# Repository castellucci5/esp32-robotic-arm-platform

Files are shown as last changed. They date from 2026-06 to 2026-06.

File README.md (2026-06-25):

# ESP32 Robotic Arm Platform

<p align="center">
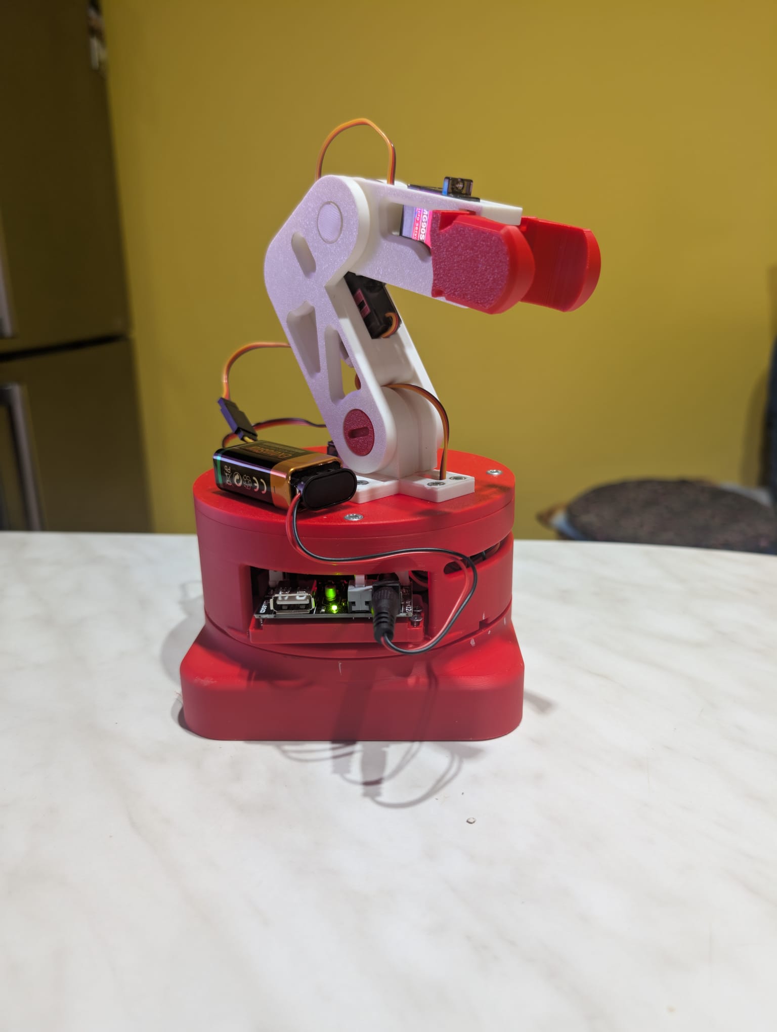
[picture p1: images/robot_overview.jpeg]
  
</p>
<p align="center">
<b>Custom evolution of the L-ONE Cyberbrick Desktop Robotic Arm</b><br>
Mechanical redesign • Embedded electronics • ESP32 firmware • Web interface
</p>

---

# Overview

This project is a complete redesign of the original **L-ONE Cyberbrick Desktop Robotic Arm**.

Instead of simply assembling the original model, the goal was to redesign the platform by improving its mechanical structure, integrating custom electronics inside the base and developing a completely new control architecture based on an ESP32 microcontroller.

The result is a cleaner, stronger and more modular robotic platform that can be controlled directly from any web browser through a local WiFi network.

---

# Why this project?

The original L-ONE Cyberbrick project is an excellent educational robotic platform.

This repository documents how it has been transformed into a completely customized version by redesigning several mechanical components, integrating embedded electronics and developing custom firmware.

Every modification presented here has been designed, manufactured and tested during the development of this project.

---

# Highlights

- 🤖 Complete mechanical redesign
- ⚡ ESP32-based control architecture
- 🌐 Browser-based WiFi control
- 🎛️ PCA9685 servo controller
- ⚙️ Stepper motor upgrade
- 🔩 Reinforced mechanical structure
- 🏗️ Internal electronics compartment
- 📚 Fully documented CAD files

---

# Mechanical Improvements

<p align="center">
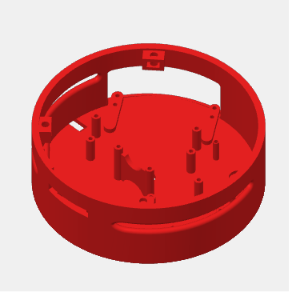
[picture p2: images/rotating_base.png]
  
</p>

Compared to the original project, the following improvements have been implemented.

## Base Assembly

- Enlarged fixed base
- Enlarged rotating base
- Internal compartment for electronics
- Integrated power distribution
- External ELEGOO power switch

## Base Rotation

<p align="center">
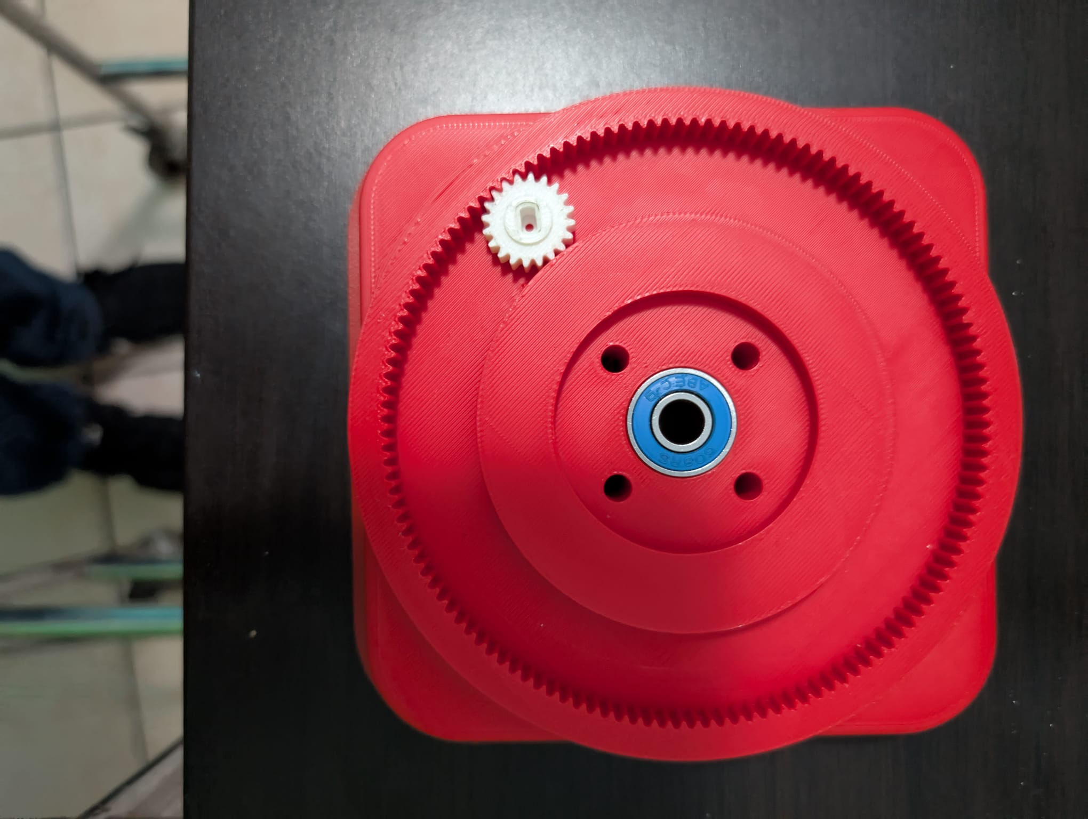
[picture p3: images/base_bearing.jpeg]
  
</p>

The rotating base has been redesigned by introducing:

- Bearing support
- 28BYJ-48 stepper motor
- ULN2003 driver
- Improved structural rigidity

## Joint 1 Redesign

<p align="center">
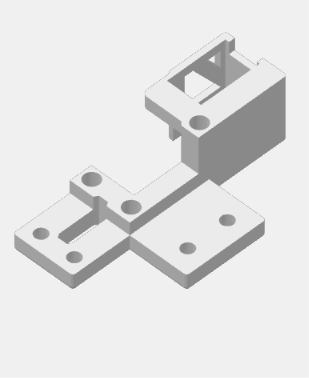
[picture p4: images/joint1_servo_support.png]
  
</p>

The original servo holder has been completely redesigned.

The servo motor is now mounted on an independent support instead of being integrated into the rotating cover.

This solution improves:

- maintenance
- accessibility
- structural rigidity

## Mechanical Reinforcement

Critical structural points have been redesigned using screw fasteners.

This solution significantly improves the robustness of the entire robotic arm compared to the original design.

---

# Electronics Integration

<p align="center">
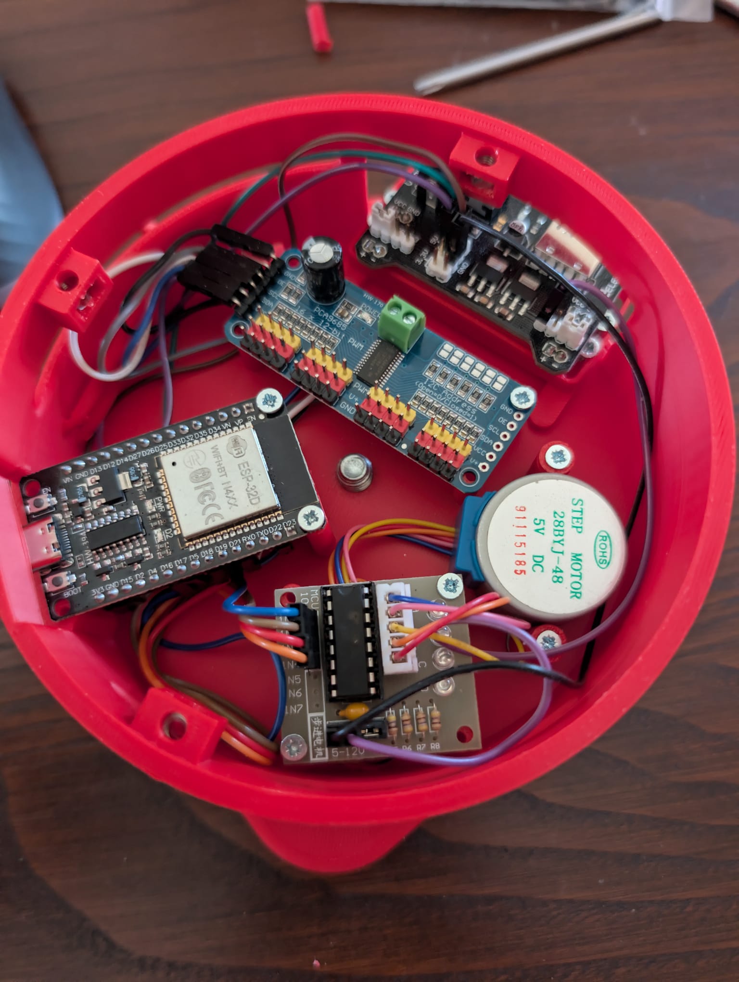
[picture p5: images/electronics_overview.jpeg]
  
</p>

The enlarged rotating base houses all control electronics.

Integrated hardware:

- ESP32
- PCA9685 Servo Driver
- ULN2003 Stepper Driver
- ELEGOO MB V2

The result is a compact and protected embedded control system.

---

# Software Architecture

<p align="center">
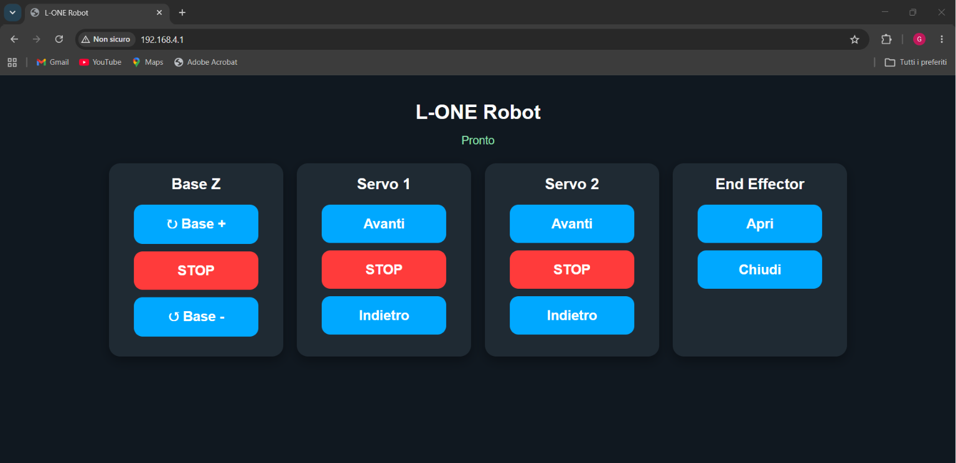
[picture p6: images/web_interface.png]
  
</p>

A completely custom firmware has been developed for ESP32.

Main features:

- Local WiFi Access Point
- Embedded Web Server
- Browser-based robot control
- Servo control
- Stepper motor control
- HTML
- CSS
- JavaScript
- LittleFS filesystem

---

# Hardware Architecture

```text
                Browser
                   │
              WiFi Network
                   │
                ESP32
        ┌──────────┴──────────┐
        │                     │
    PCA9685               ULN2003
        │                     │
 Servo Motors          Stepper Motor
```

---

# Repository Structure

```text
cad/
│
├── 3mf_files/
└── solidworks/

firmware/

images/

web_interface/
```

---

# Technologies

## Embedded

- ESP32
- Arduino Framework
- PCA9685
- ULN2003
- LittleFS

## Software

- HTML
- CSS
- JavaScript

## CAD

- SolidWorks
- Bambu Studio
- 3D Printing

## Robotics

- Servo Motors
- Stepper Motors
- Embedded Integration

---

# Project Status

## ✅ Version 1.0 — First Complete Prototype

Implemented features:

- Complete mechanical redesign
- Embedded electronics integration
- ESP32 firmware
- Browser-based control
- Ready-to-print CAD files
- Complete project documentation

---

# Future Development

## Branch A

Linear fourth axis.

## Branch B

Integration with Makerslab Arm Robot Control.

---

# Gallery

<p align="center">
  
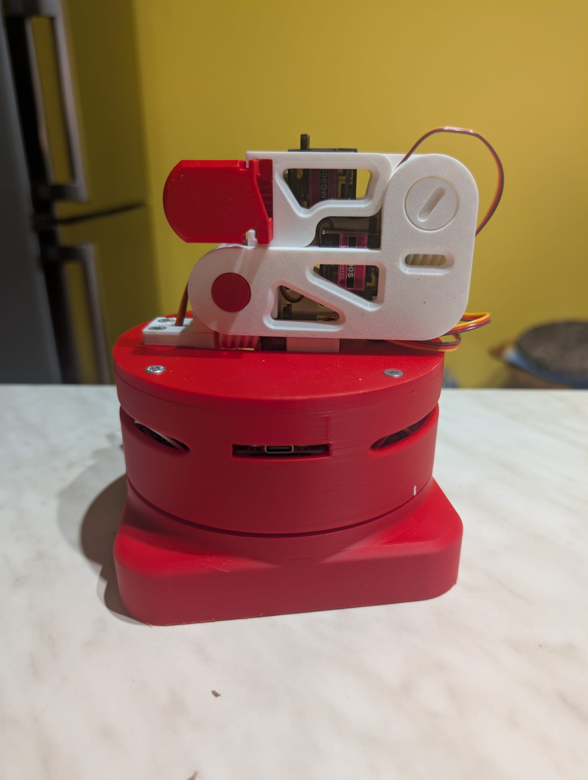
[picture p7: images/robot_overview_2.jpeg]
  
</p>

---

# Acknowledgements

This project is based on the original **L-ONE Cyberbrick Desktop Robotic Arm**.

This repository documents all custom mechanical, electronic and software developments introduced during the creation of this robotic platform.

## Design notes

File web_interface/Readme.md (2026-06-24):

# WEB PAGE

The Web page was implemented by files :
- index.html
- style.css
- script.js

These files are uploaded on ESP32 by LittleFS:
<br>
`\Arduino_Project_Directory`
- Firmware                        
`\data`
- index.html
- style.css
- script.js

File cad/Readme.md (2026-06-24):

# CAD Files

This directory contains all CAD-related resources for the project.

## Folder Structure

- `3mf/` → Bambu Studio project files
- `step/` → STEP files
- `stl/` → STL files
- `solidworks/` → Native CAD files

## Bambu Studio Files

⚠️ Some parts require a scale factor of **105%** in Bambu Studio.

Only the following files need to be scaled to 105%:

- `braccio1.3mf`
- `braccio2.3mf`
- `cover_braccio_1.3mf`
- `pinza_destra_e_sinistra_uguali.3mf`
- `ingranaggio_pinza.3mf`
- `vite_di_fissaggio_giunto_2.3mf`
- `vite_giunto_1.3mf`

All remaining files should be printed at 100% scale.

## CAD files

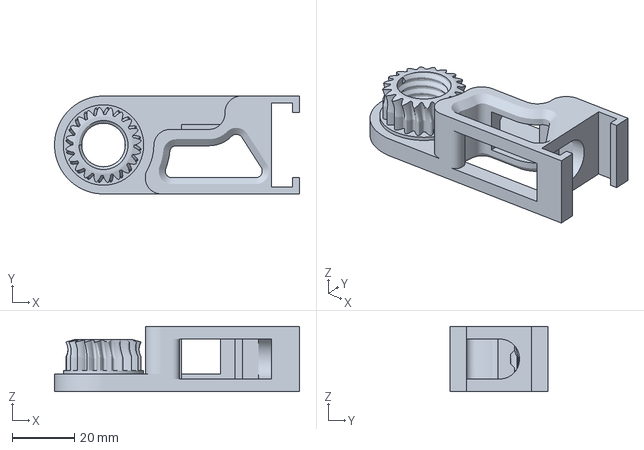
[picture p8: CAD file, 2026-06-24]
cad/3mf_files/braccio2.3mf
78.8 x 31.5 x 20.9 mm

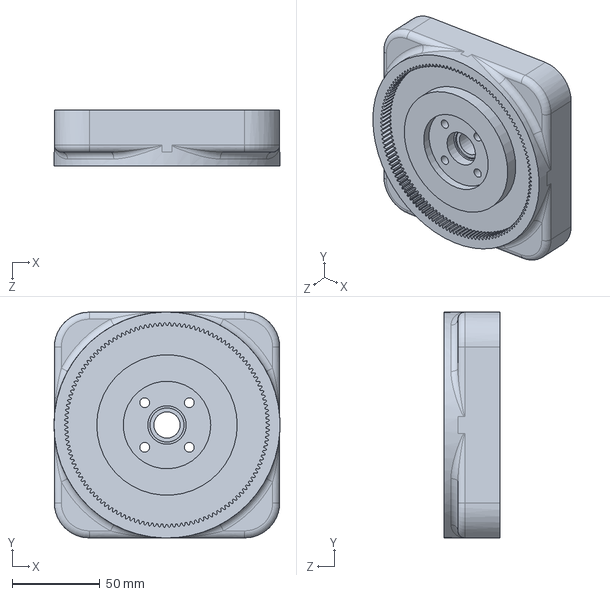
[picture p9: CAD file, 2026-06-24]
cad/solidWorks/Nuova_base.SLDPRT
129.0 x 128.9 x 32.0 mm

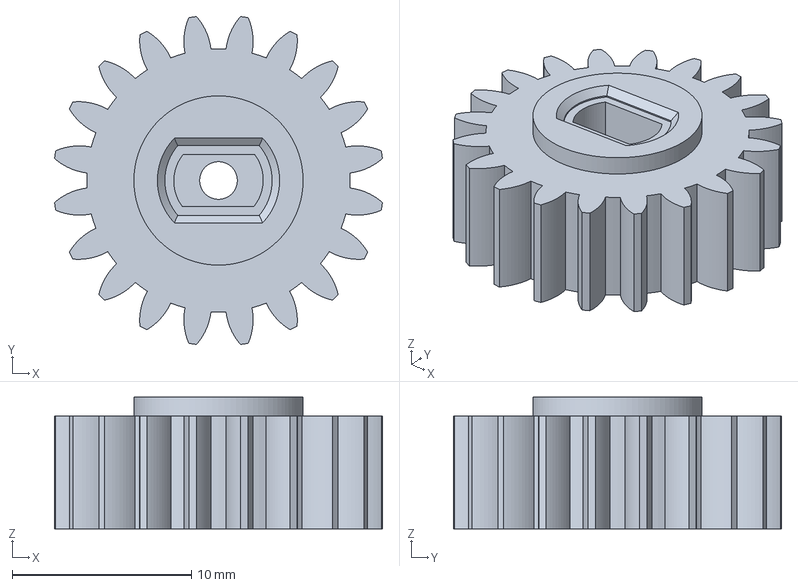
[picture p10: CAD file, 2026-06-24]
cad/3mf_files/ingranaggio_della_base.3mf
18.3 x 18.3 x 7.35 mm

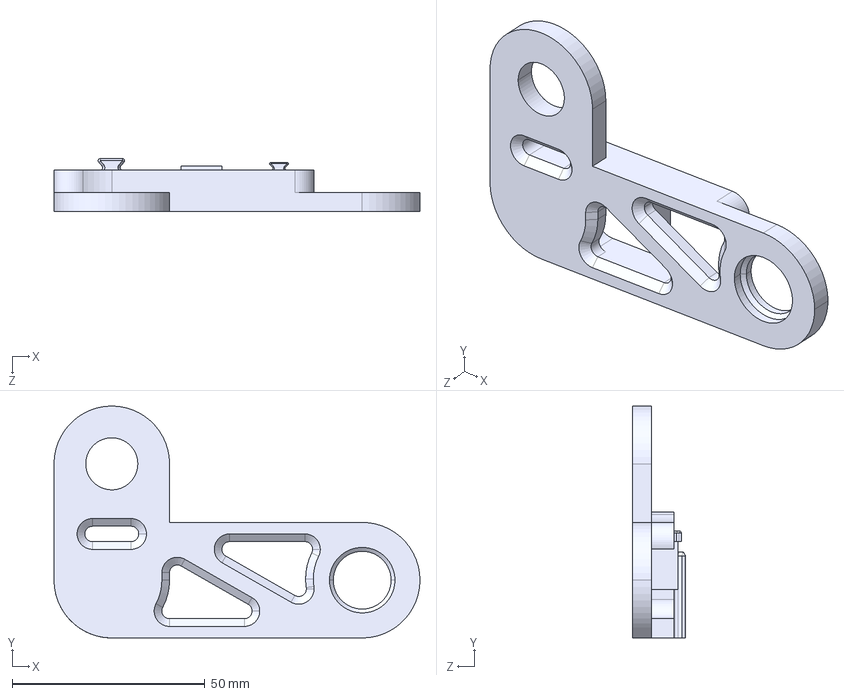
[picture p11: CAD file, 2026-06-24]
cad/solidWorks/lower_arm_cover.STEP
95.0 x 60.2 x 13.8 mm

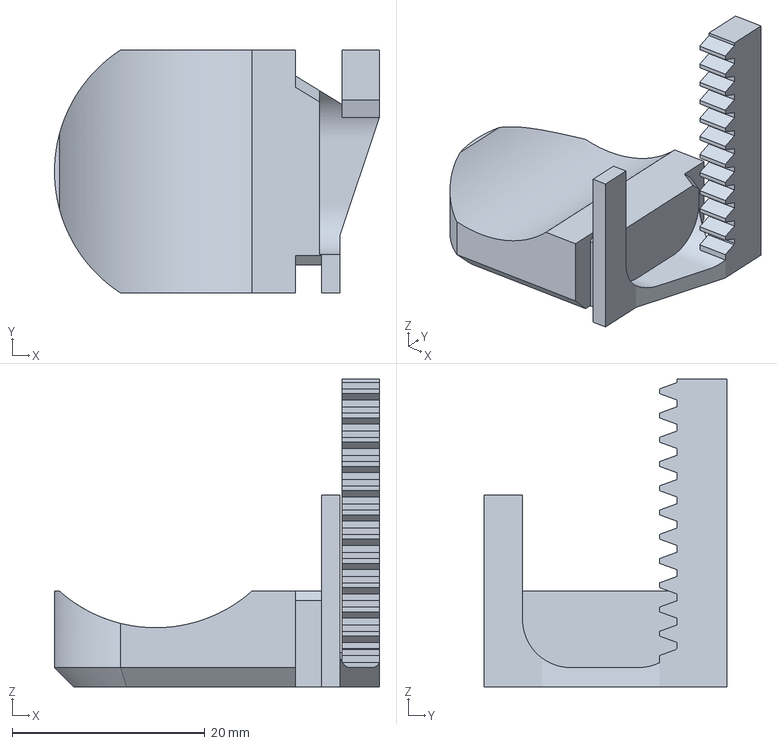
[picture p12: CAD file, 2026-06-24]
cad/3mf_files/pinza_destra_e_sinstra_uguali.3mf
33.7 x 25.2 x 31.9 mm

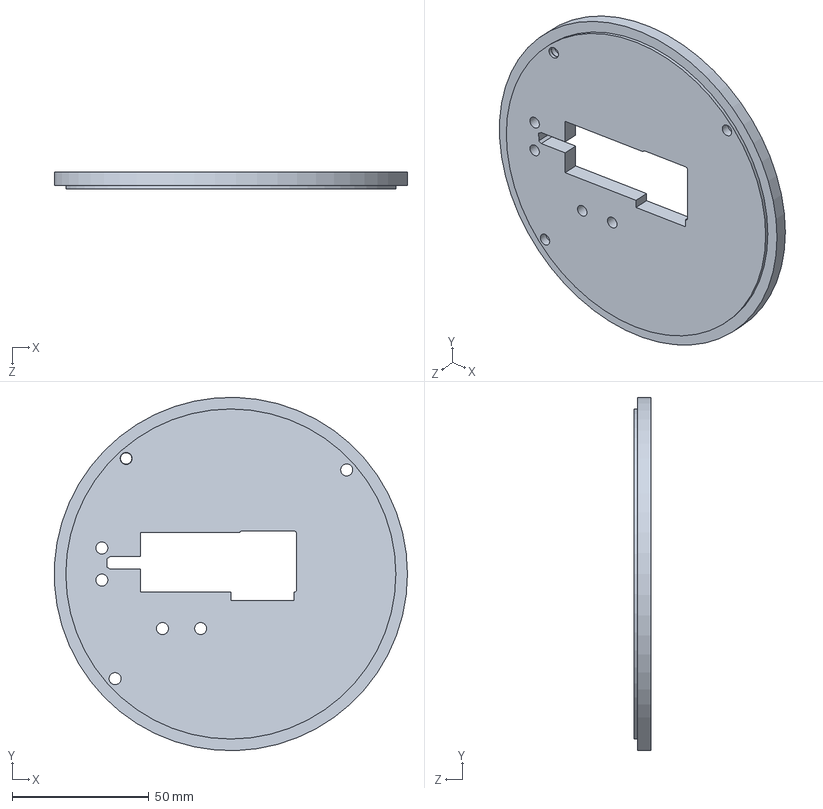
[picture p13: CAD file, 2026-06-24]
cad/solidWorks/coperchio_base.SLDPRT
128.9 x 128.9 x 6.30 mm

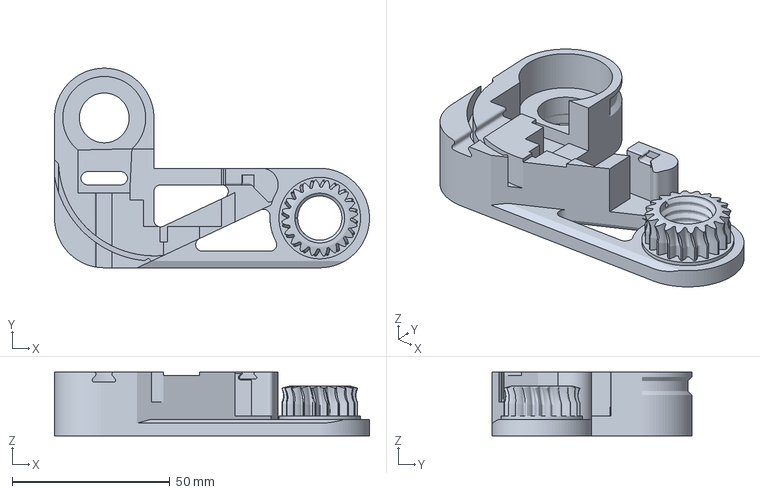
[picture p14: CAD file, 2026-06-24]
cad/3mf_files/braccio1.3mf
99.8 x 63.2 x 20.2 mm

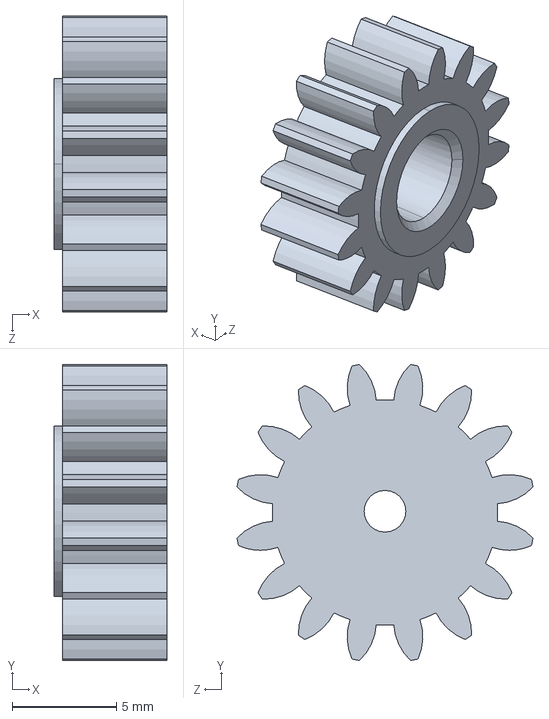
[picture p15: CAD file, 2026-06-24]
cad/solidWorks/ingranaggio_pinza.SLDPRT
5.40 x 14.2 x 14.2 mm

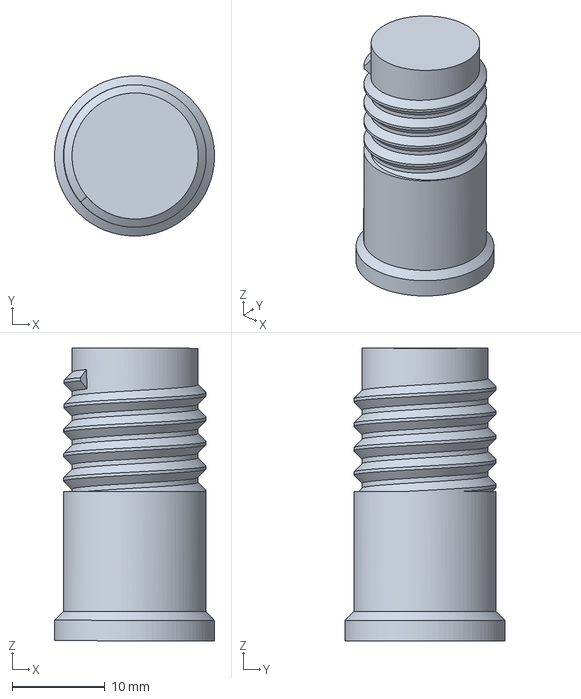
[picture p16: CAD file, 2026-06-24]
cad/3mf_files/vite_giunto_1.3mf
17.2 x 17.2 x 31.5 mm

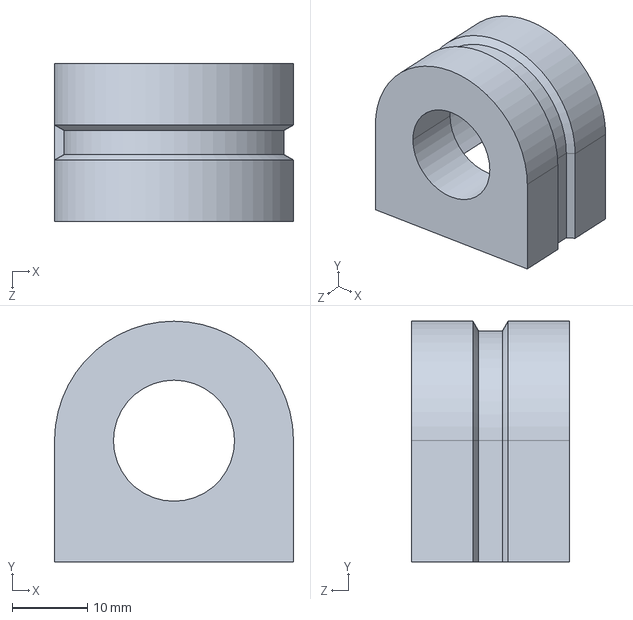
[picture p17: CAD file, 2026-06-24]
cad/solidWorks/case_giunto_1_modificato.SLDPRT
31.8 x 32.0 x 21.0 mm

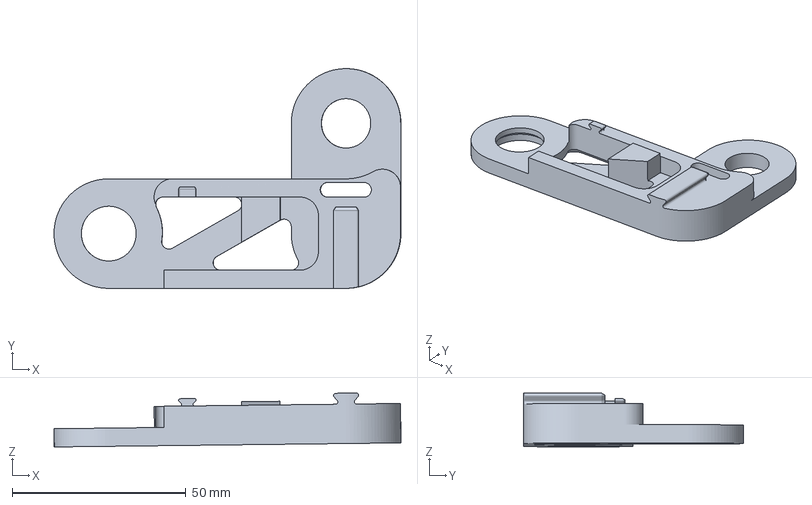
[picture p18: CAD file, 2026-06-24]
cad/3mf_files/cover_braccio_1.3mf
99.8 x 63.2 x 15.5 mm

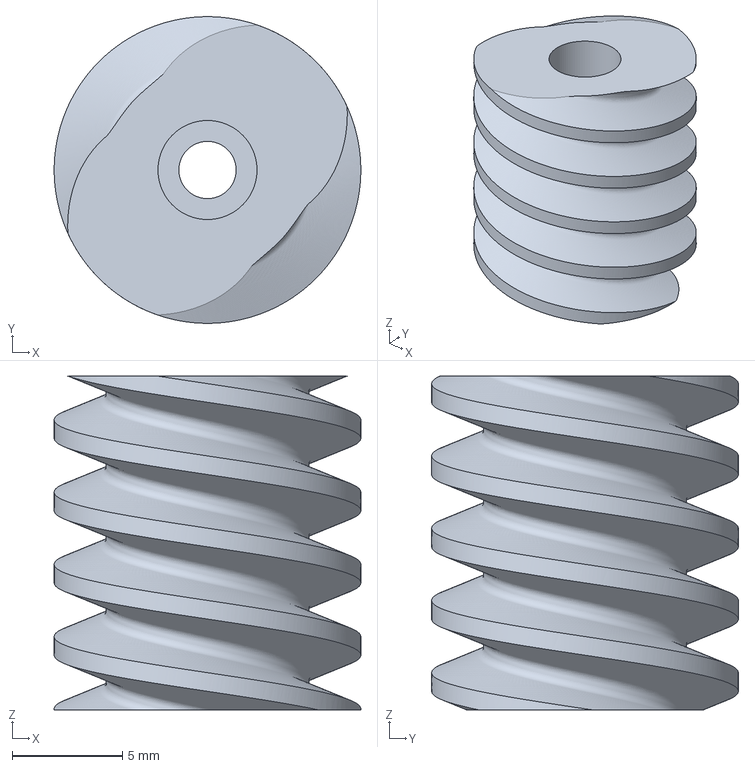
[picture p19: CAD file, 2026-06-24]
cad/3mf_files/vite_senza_fine_con_vite_di_bloccaggio.3mf
13.9 x 13.9 x 15.2 mm

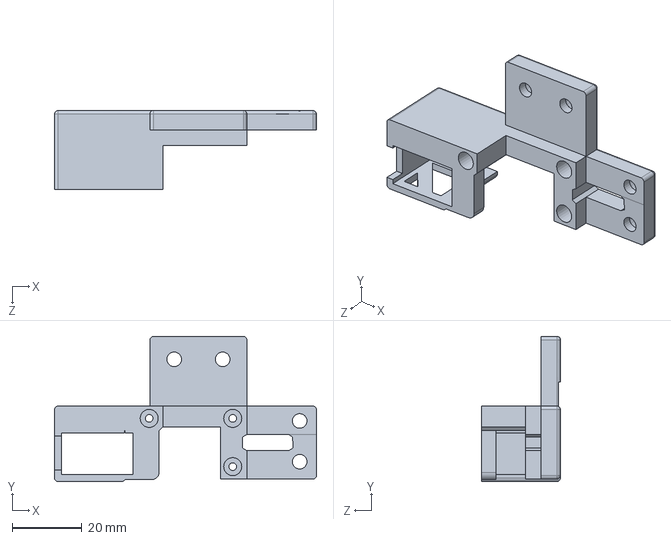
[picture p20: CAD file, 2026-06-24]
cad/solidWorks/supporto_servo_arm_1.SLDPRT
75.3 x 41.7 x 22.8 mm

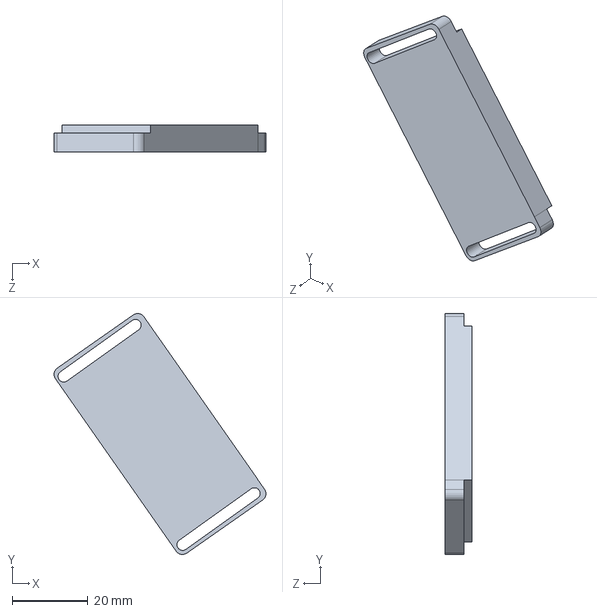
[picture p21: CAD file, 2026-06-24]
cad/solidWorks/adattatore_elego.SLDPRT
55.9 x 63.5 x 7.00 mm

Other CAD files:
cad/solidWorks/gripper_gear.STEP
cad/3mf_files/vite_di_fissaggio_giunto_2.3mf
cad/solidWorks/boccola_cuscinetto.SLDPRT
cad/solidWorks/flangia_cuscinetto_base.SLDPRT
cad/3mf_files/Nuova_base.3mf
cad/3mf_files/adattatore_elego.3mf
cad/3mf_files/base_rotante.3mf
cad/3mf_files/boccola_cuscinetto.3mf
cad/3mf_files/case_giunto_1_modificato.3mf
cad/3mf_files/coperchio_base.3mf
cad/3mf_files/fissaggio_stepper_motor.3mf
cad/3mf_files/flangia_cuscinetto_base.3mf
cad/3mf_files/ingranaggio_pinza.3mf
cad/3mf_files/supporto_servo_arm_1.3mf
cad/solidWorks/Vite_senza_fine_con_fissaggio.SLDPRT
cad/solidWorks/base_rotante.SLDPRT
cad/solidWorks/fissaggio_stepper_motor.SLDPRT
cad/solidWorks/gripper_left_right_same.STEP
cad/solidWorks/lower_arm_screw.STEP
cad/solidWorks/upper_arm_screw.STEP

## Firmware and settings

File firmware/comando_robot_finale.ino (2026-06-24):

#include <WiFi.h>
#include <Wire.h>
// #include <Stepper.h>
#include <AccelStepper.h>
#include <Adafruit_PWMServoDriver.h>
#include <LittleFS.h>

// ===== WiFi =====
const char* ssid = "LONE_ROBOT";
const char* password = "12345678";

WiFiServer server(80);

// ===== PCA9685 =====
Adafruit_PWMServoDriver pwm = Adafruit_PWMServoDriver(0x40);

#define SERVO_FREQ 50

#define SERVO1_CH 0
#define SERVO2_CH 1
#define GRIPPER_CH 2

// Servo 1
#define SERVO1_STOP_US 1480
#define SERVO1_FWD_US  800
#define SERVO1_REV_US  2300

// Servo 2
#define SERVO2_STOP_US 1500
#define SERVO2_FWD_US  1850
#define SERVO2_REV_US  1300

// Gripper 180°
#define GRIPPER_OPEN_US   1600
#define GRIPPER_CLOSE_US  750

// ===== Stepper 28BYJ-48 + ULN2003 =====
const int IN1 = 16;
const int IN2 = 18;
const int IN3 = 17;
const int IN4 = 19;

//const int stepsPerRevolution = 2048;

const float BASE_SPEED = 512; // circa equivalente a 15 rpm con 2048 step/rev default 1024


// Ordine fasi trovato funzionante
//Stepper baseStepper(stepsPerRevolution, IN1, IN4, IN3, IN2);
// Ordine fasi trovato funzionante

AccelStepper baseStepper(AccelStepper::HALF4WIRE, IN1, IN4, IN3, IN2);

// int baseSpeedRpm = 15;

// Da calibrazione:
// 3500 step ≈ 90°
// quindi 1750 step ≈ 45°
#define BASE_45_STEPS 1750

// ===== Funzioni =====
int usToTicks(int us) {
  return (int)(us * 4096L / 20000L);
}

void writeServoUS(int ch, int us) {
  pwm.setPWM(ch, 0, usToTicks(us));
}

void releaseStepper() {
  baseStepper.setSpeed(0);

  digitalWrite(16, LOW);
  digitalWrite(17, LOW);
  digitalWrite(18, LOW);
  digitalWrite(19, LOW);
}

void setup() {
  Serial.begin(115200);
  // Montaggio del file system
  LittleFS.begin(true);
  // I2C ESP32
  Wire.begin(21, 22);

  // PCA9685
  pwm.begin();
  pwm.setPWMFreq(SERVO_FREQ);
  delay(500);

  writeServoUS(SERVO1_CH, SERVO1_STOP_US);
  writeServoUS(SERVO2_CH, SERVO2_STOP_US);
  writeServoUS(GRIPPER_CH, GRIPPER_OPEN_US);

  // Stepper
  pinMode(16, OUTPUT);
  pinMode(17, OUTPUT);
  pinMode(18, OUTPUT);
  pinMode(19, OUTPUT);

  //baseStepper.setSpeed(baseSpeedRpm);
  //releaseStepper();

  baseStepper.setMaxSpeed(BASE_SPEED);
  baseStepper.setSpeed(0);

  

  // WiFi AP
  WiFi.softAP(ssid, password);

  Serial.println("WiFi creato");
  Serial.print("Connettiti a: ");
  Serial.println(ssid);
  Serial.print("Apri browser su: http://");
  Serial.println(WiFi.softAPIP());

  server.begin();
}

void loop() {
  baseStepper.runSpeed();
  
  WiFiClient client = server.available();
  if (!client) return;

  String req = client.readStringUntil('\r');
  client.flush();

  String path = req.substring(req.indexOf("GET ") + 4, req.indexOf(" HTTP"));

  if (path == "/BASE_P") {
    baseStepper.setSpeed(BASE_SPEED);
    sendText(client, "BASE +");
  }
  else if (path == "/BASE_M") {
    baseStepper.setSpeed(-BASE_SPEED);
    sendText(client, "BASE -");
  }
  else if (path == "/BASE_STOP") {
    releaseStepper();
    sendText(client, "BASE STOP");
  }
  else if (path == "/S1A") {
    writeServoUS(SERVO1_CH, SERVO1_FWD_US);
    sendText(client, "SERVO 1 AVANTI");
  }
  else if (path == "/S1S") {
    writeServoUS(SERVO1_CH, SERVO1_STOP_US);
    sendText(client, "SERVO 1 STOP");
  }
  else if (path == "/S1D") {
    writeServoUS(SERVO1_CH, SERVO1_REV_US);
    sendText(client, "SERVO 1 INDIETRO");
  }
  else if (path == "/S2A") {
    writeServoUS(SERVO2_CH, SERVO2_FWD_US);
    sendText(client, "SERVO 2 AVANTI");
  }
  else if (path == "/S2S") {
    writeServoUS(SERVO2_CH, SERVO2_STOP_US);
    sendText(client, "SERVO 2 STOP");
  }
  else if (path == "/S2D") {
    writeServoUS(SERVO2_CH, SERVO2_REV_US);
    sendText(client, "SERVO 2 INDIETRO");
  }
  else if (path == "/OPEN") {
    writeServoUS(GRIPPER_CH, GRIPPER_OPEN_US);
    sendText(client, "GRIPPER APERTO");
  }
  else if (path == "/CLOSE") {
    writeServoUS(GRIPPER_CH, GRIPPER_CLOSE_US);
    sendText(client, "GRIPPER CHIUSO");
  }
  else if (path == "/style.css") {
    serveFile(client, "/style.css", "text/css");
  }
  else if (path == "/script.js") {
    serveFile(client, "/script.js", "application/javascript");
  }
  else {
    serveFile(client, "/index.html", "text/html");
  }
  

  // ===== BASE =====
  //   if (req.indexOf("/BASE_P") != -1) {
  //   Serial.println("BASE ORARIO CONTINUO");
  //   baseStepper.setSpeed(BASE_SPEED);
  // }
  
  // if (req.indexOf("/BASE_M") != -1) {
  //   Serial.println("BASE ANTIORARIO CONTINUO");
  //   baseStepper.setSpeed(-BASE_SPEED);
  // }
  
  // if (req.indexOf("/BASE_STOP") != -1) {
  //   Serial.println("BASE STOP");
  //   releaseStepper();
  // }

  // // ===== SERVO 1 =====
  // if (req.indexOf("/S1A") != -1) {
  //   writeServoUS(SERVO1_CH, SERVO1_FWD_US);
  //   Serial.println("SERVO 1 AVANTI");
  // }

  // if (req.indexOf("/S1S") != -1) {
  //   writeServoUS(SERVO1_CH, SERVO1_STOP_US);
  //   Serial.println("SERVO 1 STOP");
  // }

  // if (req.indexOf("/S1D") != -1) {
  //   writeServoUS(SERVO1_CH, SERVO1_REV_US);
  //   Serial.println("SERVO 1 INDIETRO");
  // }

  // // ===== SERVO 2 =====
  // if (req.indexOf("/S2A") != -1) {
  //   writeServoUS(SERVO2_CH, SERVO2_FWD_US);
  //   Serial.println("SERVO 2 AVANTI");
  // }

  // if (req.indexOf("/S2S") != -1) {
  //   writeServoUS(SERVO2_CH, SERVO2_STOP_US);
  //   Serial.println("SERVO 2 STOP");
  // }

  // if (req.indexOf("/S2D") != -1) {
  //   writeServoUS(SERVO2_CH, SERVO2_REV_US);
  //   Serial.println("SERVO 2 INDIETRO");
  // }

  // // ===== GRIPPER =====
  // if (req.indexOf("/OPEN") != -1) {
  //   writeServoUS(GRIPPER_CH, GRIPPER_OPEN_US);
  //   Serial.println("GRIPPER APERTO");
  // }

  // if (req.indexOf("/CLOSE") != -1) {
  //   writeServoUS(GRIPPER_CH, GRIPPER_CLOSE_US);
  //   Serial.println("GRIPPER CHIUSO");
  // }

  // ===== PAGINA WEB =====
  // File f = LittleFS.open("/index.html", "r");

  // client.println("HTTP/1.1 200 OK");
  // client.println("Content-Type: text/html");
  // client.println();

  // while (f.available()) {
  //     client.write(f.read());
  // }

  // f.close();

  // client.println("HTTP/1.1 200 OK");
  // client.println("Content-type:text/html");
  // client.println();

  // client.println("<!DOCTYPE html><html>");
  // client.println("<head><meta name='viewport' content='width=device-width, initial-scale=1'>");

  // client.println("<style>");
  // client.println("body{font-family:Arial;text-align:center;margin-top:25px;}");
  // client.println(".container{display:flex;justify-content:center;gap:25px;flex-wrap:wrap;}");
  // client.println(".box{border:1px solid #999;border-radius:12px;padding:18px;width:260px;}");
  // client.println("button{font-size:24px;padding:18px;margin:8px;width:210px;}");
  // client.println("</style></head>");

  // client.println("<body>");
  // client.println("<h1>L-ONE Robot Test</h1>");

  // client.println("<div class='container'>");

  // client.println("<div class='box'>");
  // client.println("<h2>Base Z</h2>");
  // client.println("<p><a href='/BASE_P'><button>+</button></a></p>");
  // client.println("<p><a href='/BASE_STOP'><button>STOP</button></a></p>");
  // client.println("<p><a href='/BASE_M'><button>-</button></a></p>");
  // client.println("</div>");

  // client.println("<div class='box'>");
  // client.println("<h2>Servo 1</h2>");
  // client.println("<p><a href='/S1A'><button>AVANTI</button></a></p>");
  // client.println("<p><a href='/S1S'><button>STOP</button></a></p>");
  // client.println("<p><a href='/S1D'><button>INDIETRO</button></a></p>");
  // client.println("</div>");

  // client.println("<div class='box'>");
  // client.println("<h2>Servo 2</h2>");
  // client.println("<p><a href='/S2A'><button>AVANTI</button></a></p>");
  // client.println("<p><a href='/S2S'><button>STOP</button></a></p>");
  // client.println("<p><a href='/S2D'><button>INDIETRO</button></a></p>");
  // client.println("</div>");

  // client.println("<div class='box'>");
  // client.println("<h2>End Effector</h2>");
  // client.println("<p><a href='/OPEN'><button>APRI</button></a></p>");
  // client.println("<p><a href='/CLOSE'><button>CHIUDI</button></a></p>");
  // client.println("</div>");

  // client.println("</div>");
  // client.println("</body></html>");

  // client.println();
}

void sendText(WiFiClient &client, String msg) {
  client.println("HTTP/1.1 200 OK");
  client.println("Content-Type: text/plain");
  client.println();
  client.println(msg);
  client.stop();
}

void serveFile(WiFiClient &client, const char* path, const char* type) {
  File f = LittleFS.open(path, "r");

  if (!f) {
    client.println("HTTP/1.1 404 Not Found");
    client.println("Content-Type: text/plain");
    client.println();
    client.println("File non trovato");
    client.stop();
    return;
  }

  client.println("HTTP/1.1 200 OK");
  client.print("Content-Type: ");
  client.println(type);
  client.println();

  while (f.available()) {
    client.write(f.read());
  }

  f.close();
  client.stop();
}

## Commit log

2026-06-24 Create CAD
2026-06-24 added .3mf files
    .3mf files with Bambu studio configuration
    [Nuova_base.3mf, adattatore_elego.3mf, base_rotante.3mf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]
2026-06-24 Added SolidWorks files
    .STEP files are the original project
    .SLDPRT files are modified
    [Nuova_base.SLDPRT, Vite_senza_fine_con_fissaggio.SLDPRT, adattatore_elego.SLDPRT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]
2026-06-24 added cad Photo
2026-06-24 added firmware from arduino ide
2026-06-25 deleted solidWork
    [case_giunto_1_modificato.SLDPRT, coperchio_base.SLDPRT, fissaggio_stepper_motor.SLDPRT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]
